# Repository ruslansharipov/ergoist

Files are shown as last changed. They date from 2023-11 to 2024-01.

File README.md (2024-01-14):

# Ergoist
Ergonomic fully split wireless keyboard

Main features: 
- ortholinear layout with 42 keys including 3 keys thumb cluster (just like on corne)
- all keys are 1u to make it easier to find keycaps
- pcb has big cutaway for battery, that can fit 35x30 lipo battery (should fit lipo 503035 500mA)
- designed to be used with Seeduino Xiao
- wireless only. Wired version will be supported it in future
- no screen integration (yet?)
- power switch (longer battery life, no accidental presses during transportation)
- works with ZMK, latest config can be found [here](https://github.com/ruslansharipov/ergoist-zmk-config)
- reversible PCB makes it cheaper in production (usually you can't order less than 5 pieces, so having 5 of those will make you able to assemble 2.5 keyboards)

Status:
- ~~pcb v0.1 in production~~ received, assembled, tested
- case **re**design

Latest images:
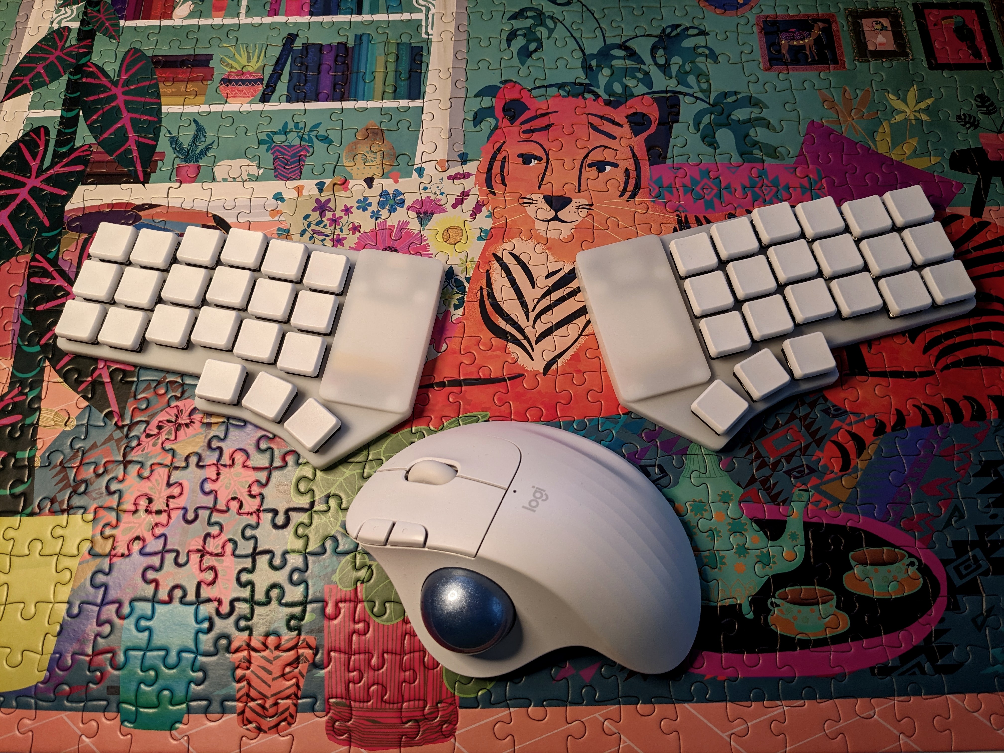
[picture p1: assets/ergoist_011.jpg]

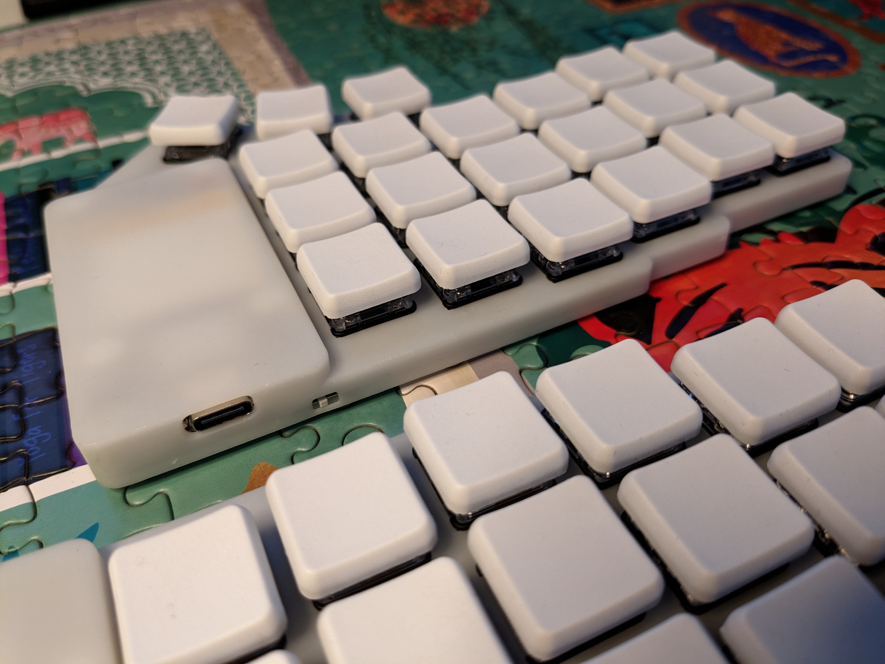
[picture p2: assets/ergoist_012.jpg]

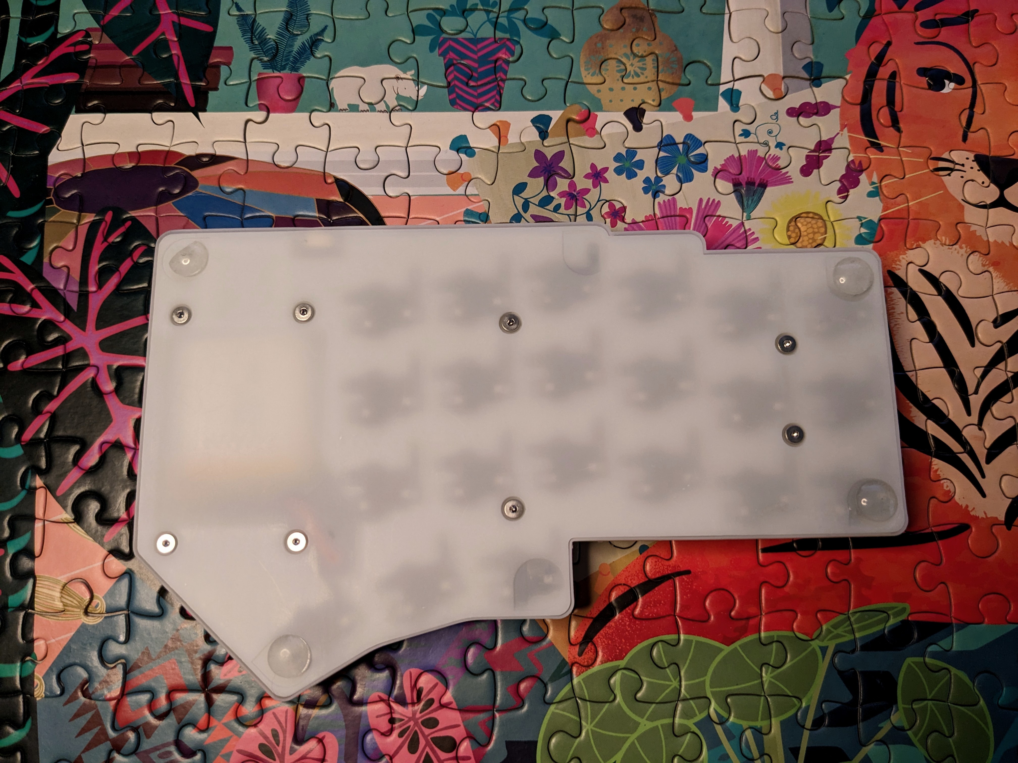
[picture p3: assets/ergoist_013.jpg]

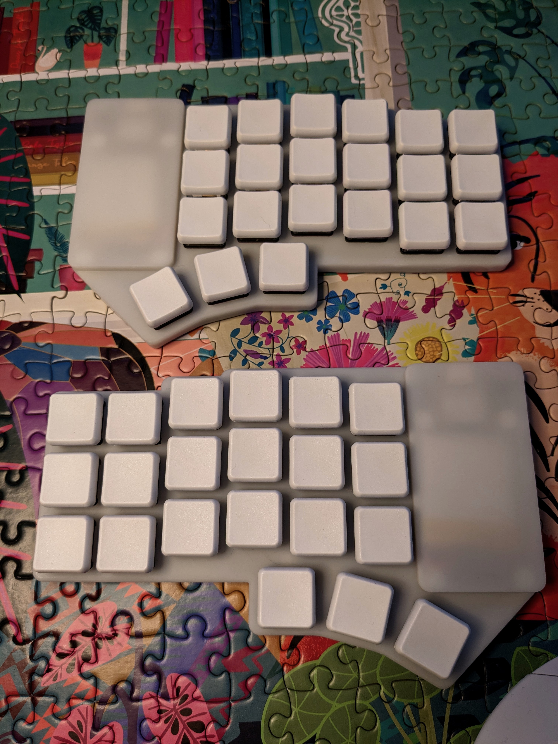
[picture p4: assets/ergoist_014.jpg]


TODO
- update case design
- pcb cleanup
- partlist
- wired version
- screen integration
- touch sensor integration

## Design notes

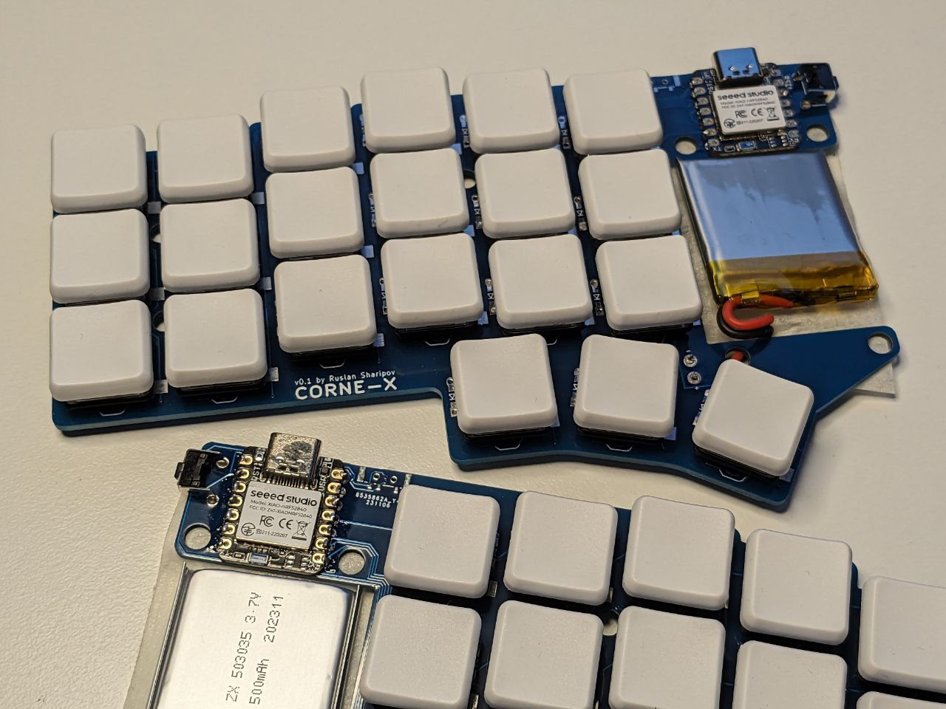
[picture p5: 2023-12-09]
assets/msg270168496-207824.jpg

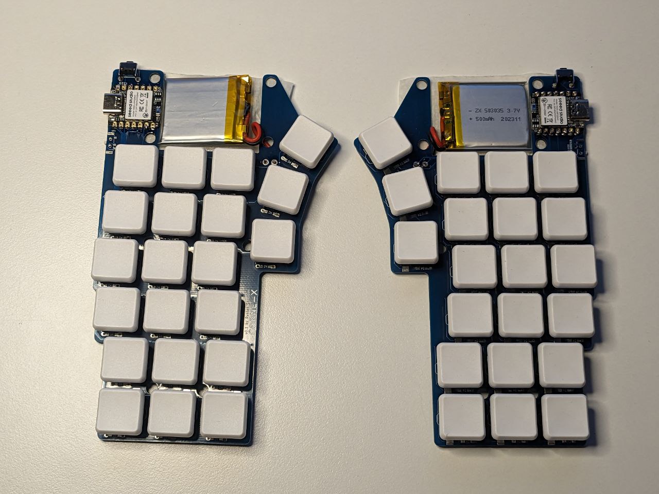
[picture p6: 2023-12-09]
assets/msg270168496-207822.jpg

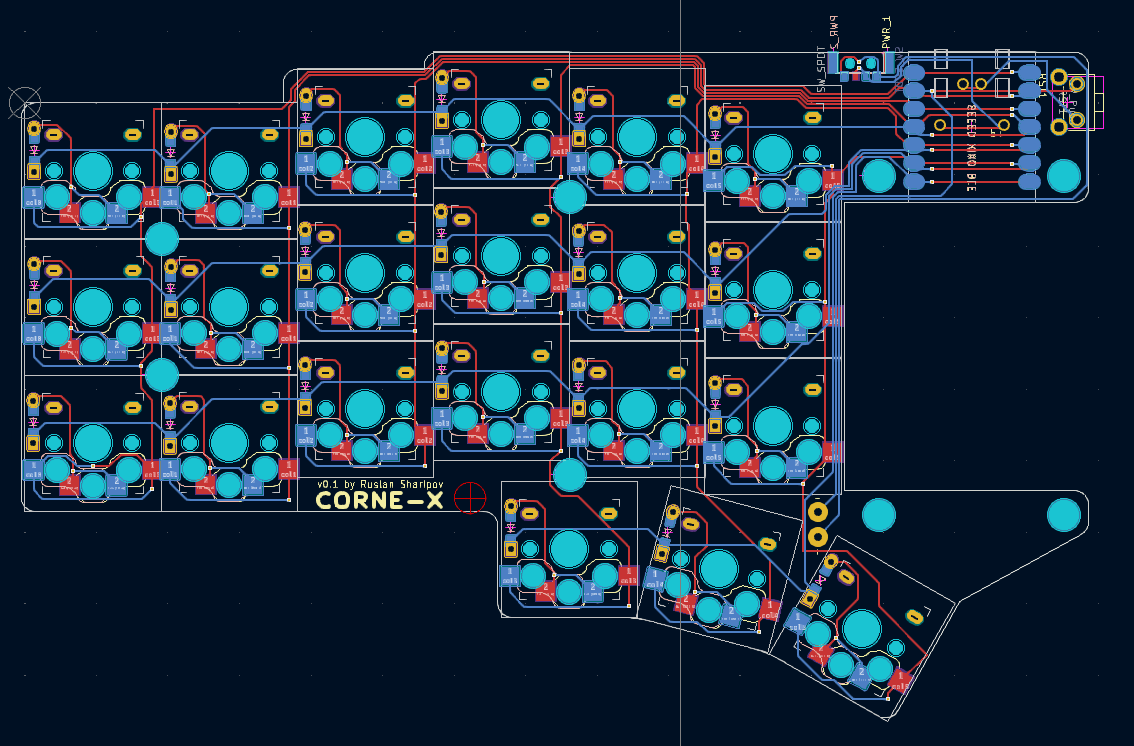
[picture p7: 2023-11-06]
assets/Screenshot 2023-11-06 at 20.16.44.png

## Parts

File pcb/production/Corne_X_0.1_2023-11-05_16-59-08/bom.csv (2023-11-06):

Designator | Footprint | Quantity | Value | LCSC Part #
_8, _7, _6, _5, _4, _3, _2, |  | 8
BAT+1 | BatteryPad | 1 | +
BATGND1 | BatteryPad | 1 | -
D1, D10, D11, D12, D13, D14, D15, D16, D17, D18, D19, D2, D20, D21, D3, D4, D5, D6, D7, D8, D9 | D3_TH_reversible | 21 | D
PWR_1, PWR_2 | MSK12C02 | 2 | SW_SPDT
RST1 | SKHLLCA010_reversible | 1 | SW_Push
SW1, SW10, SW11, SW12, SW13, SW14, SW15, SW16, SW17, SW18, SW19, SW2, SW20, SW21, SW3, SW4, SW5, SW6, SW7, SW8, SW9 | keyswitch_chock12_hotswap_1u_reversible | 21 | SW_PUSH
U1, U4 | xiao-ble-smd-cutout-one-side | 2 | xiao-ble

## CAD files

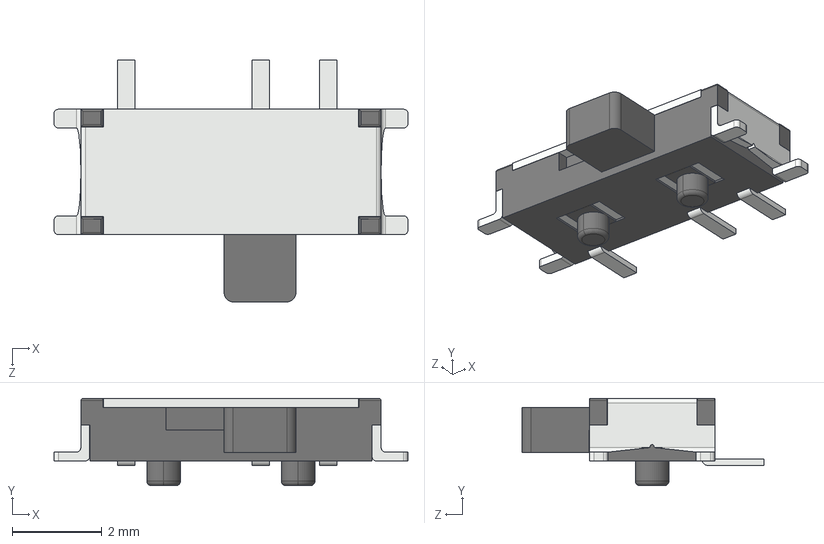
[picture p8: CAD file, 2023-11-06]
pcb/kbd/TOTEM3D/MSK12C02.STEP
7.90 x 1.95 x 5.39 mm

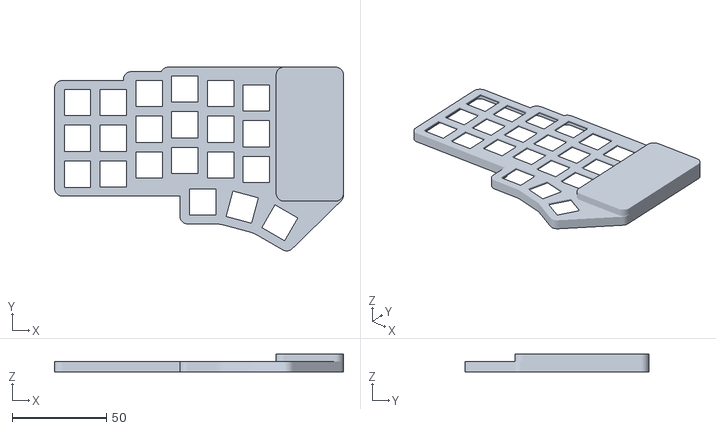
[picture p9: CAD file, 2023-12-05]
pcb/svg/Body11.stl
153.6 x 97.7 x 9.50

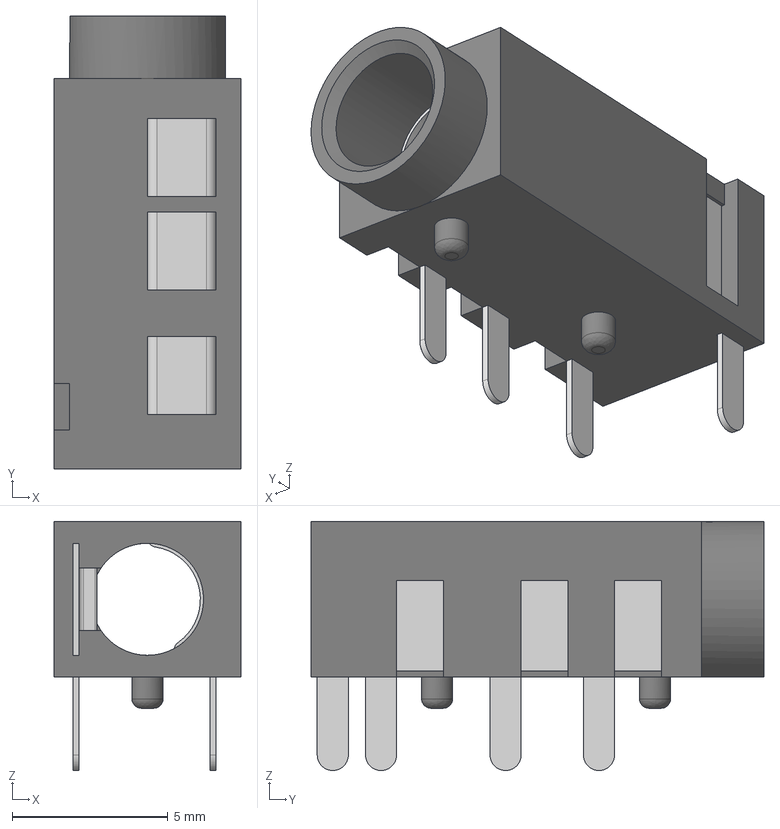
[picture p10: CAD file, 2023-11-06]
pcb/kbd/TOTEM3D/PJ320A.STEP
6.00 x 14.6 x 8.00 mm

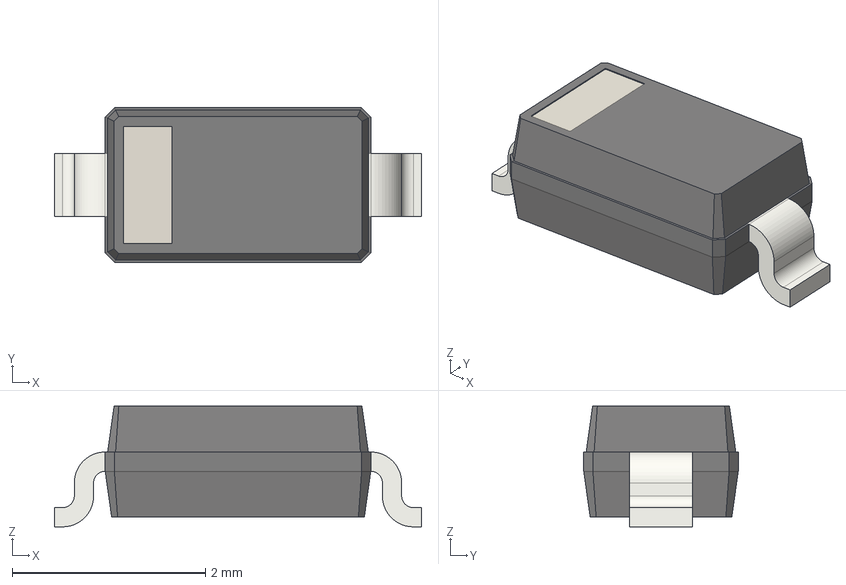
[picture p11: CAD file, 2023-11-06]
pcb/kbd/TOTEM3D/D_SOD-123.step
3.80 x 1.60 x 1.25 mm

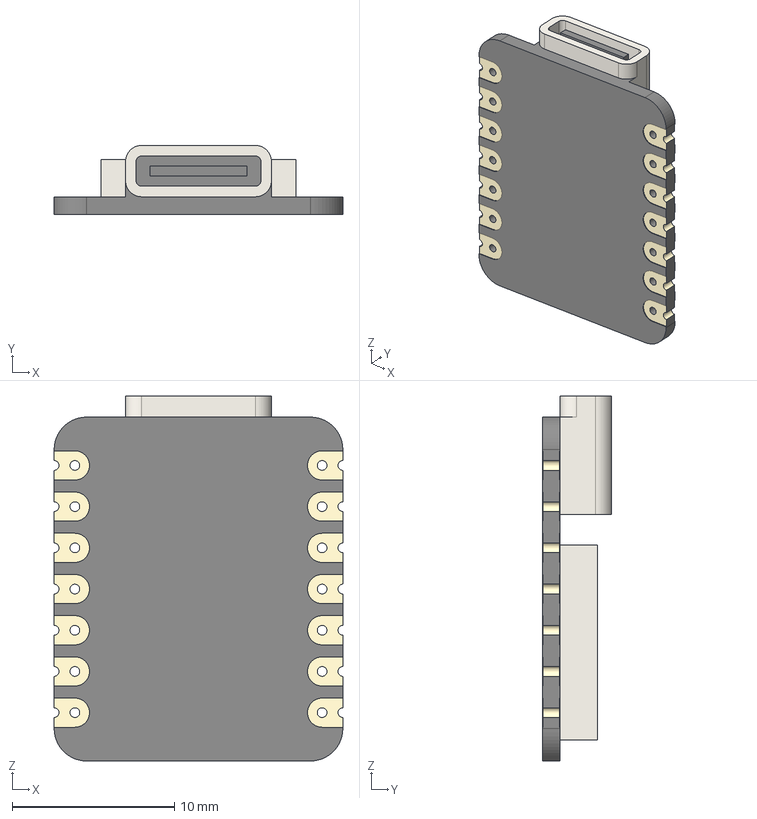
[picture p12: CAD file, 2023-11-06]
pcb/kbd/TOTEM3D/xiao-ble-tht.step
17.8 x 4.27 x 22.5 mm

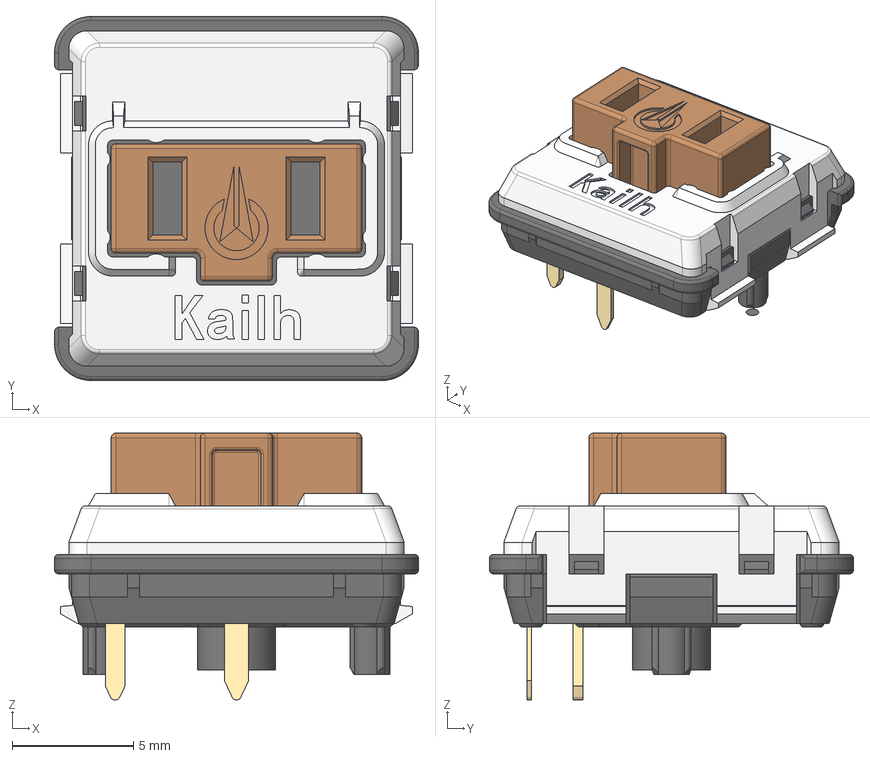
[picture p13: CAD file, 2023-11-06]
pcb/kbd/TOTEM3D/Kailh_switch_PG1350_optional.step
15.0 x 15.0 x 11.0 mm

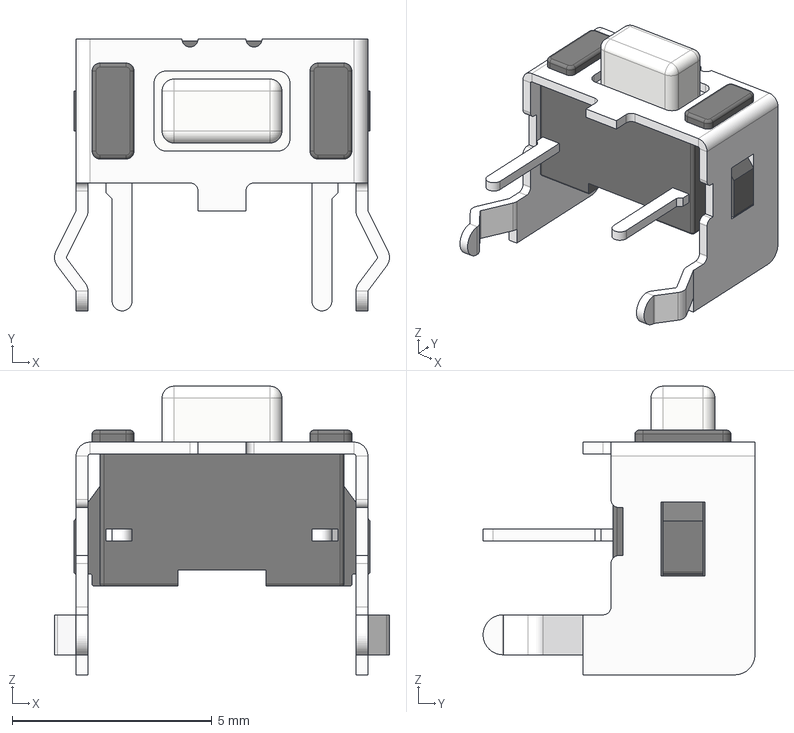
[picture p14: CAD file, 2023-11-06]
pcb/kbd/TOTEM3D/SW_SKHLLC.step
8.38 x 6.80 x 7.22 mm

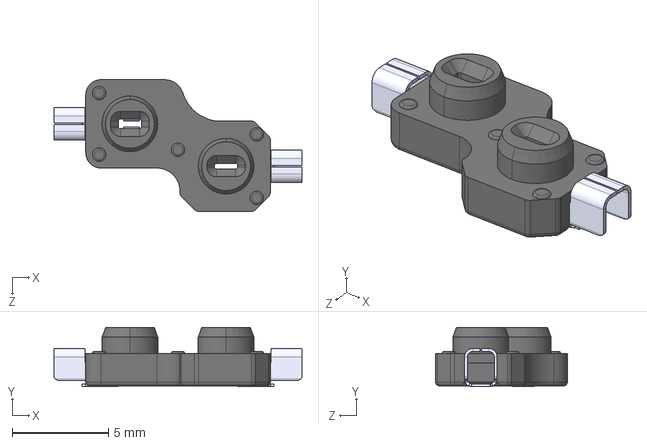
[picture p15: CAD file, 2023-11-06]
pcb/kbd/TOTEM3D/Kailh_socket_PG1350_optional.STEP
12.9 x 3.09 x 6.85 mm
pin x 2
socket

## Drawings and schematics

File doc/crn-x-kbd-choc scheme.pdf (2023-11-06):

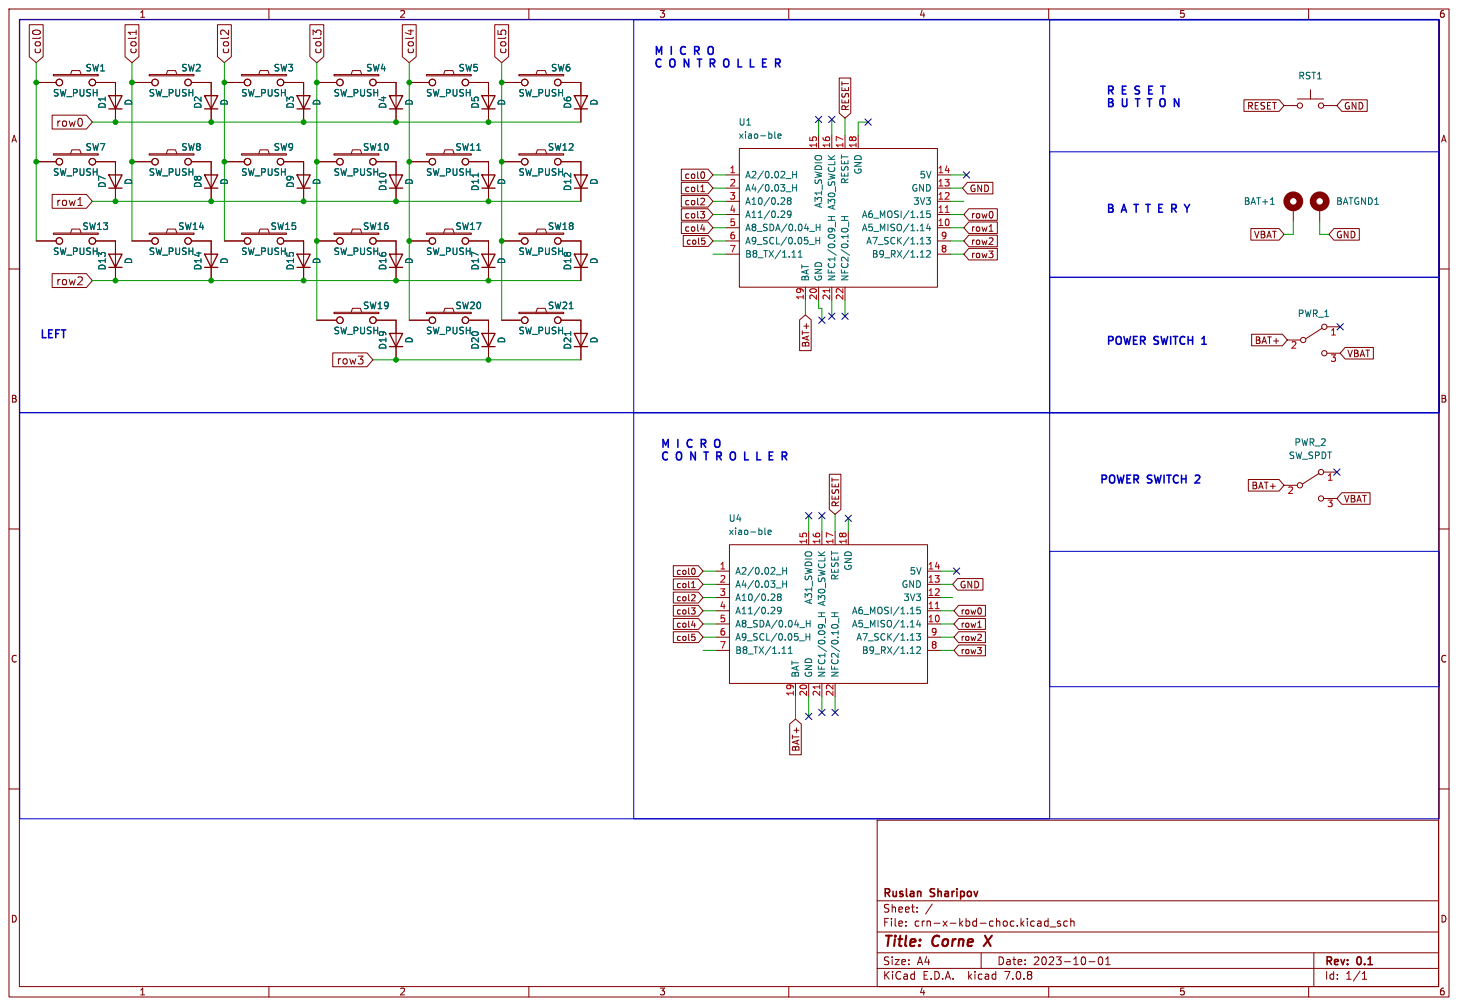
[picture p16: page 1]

POWER SWITCH 1 POWER SWITCH 2 M I C R O

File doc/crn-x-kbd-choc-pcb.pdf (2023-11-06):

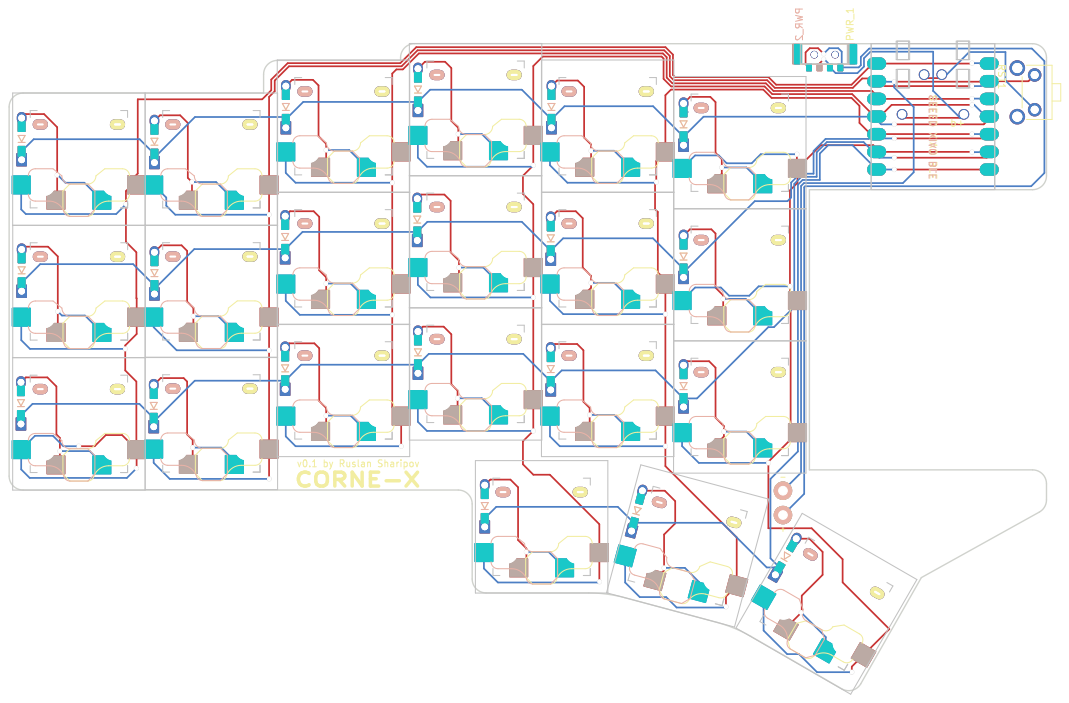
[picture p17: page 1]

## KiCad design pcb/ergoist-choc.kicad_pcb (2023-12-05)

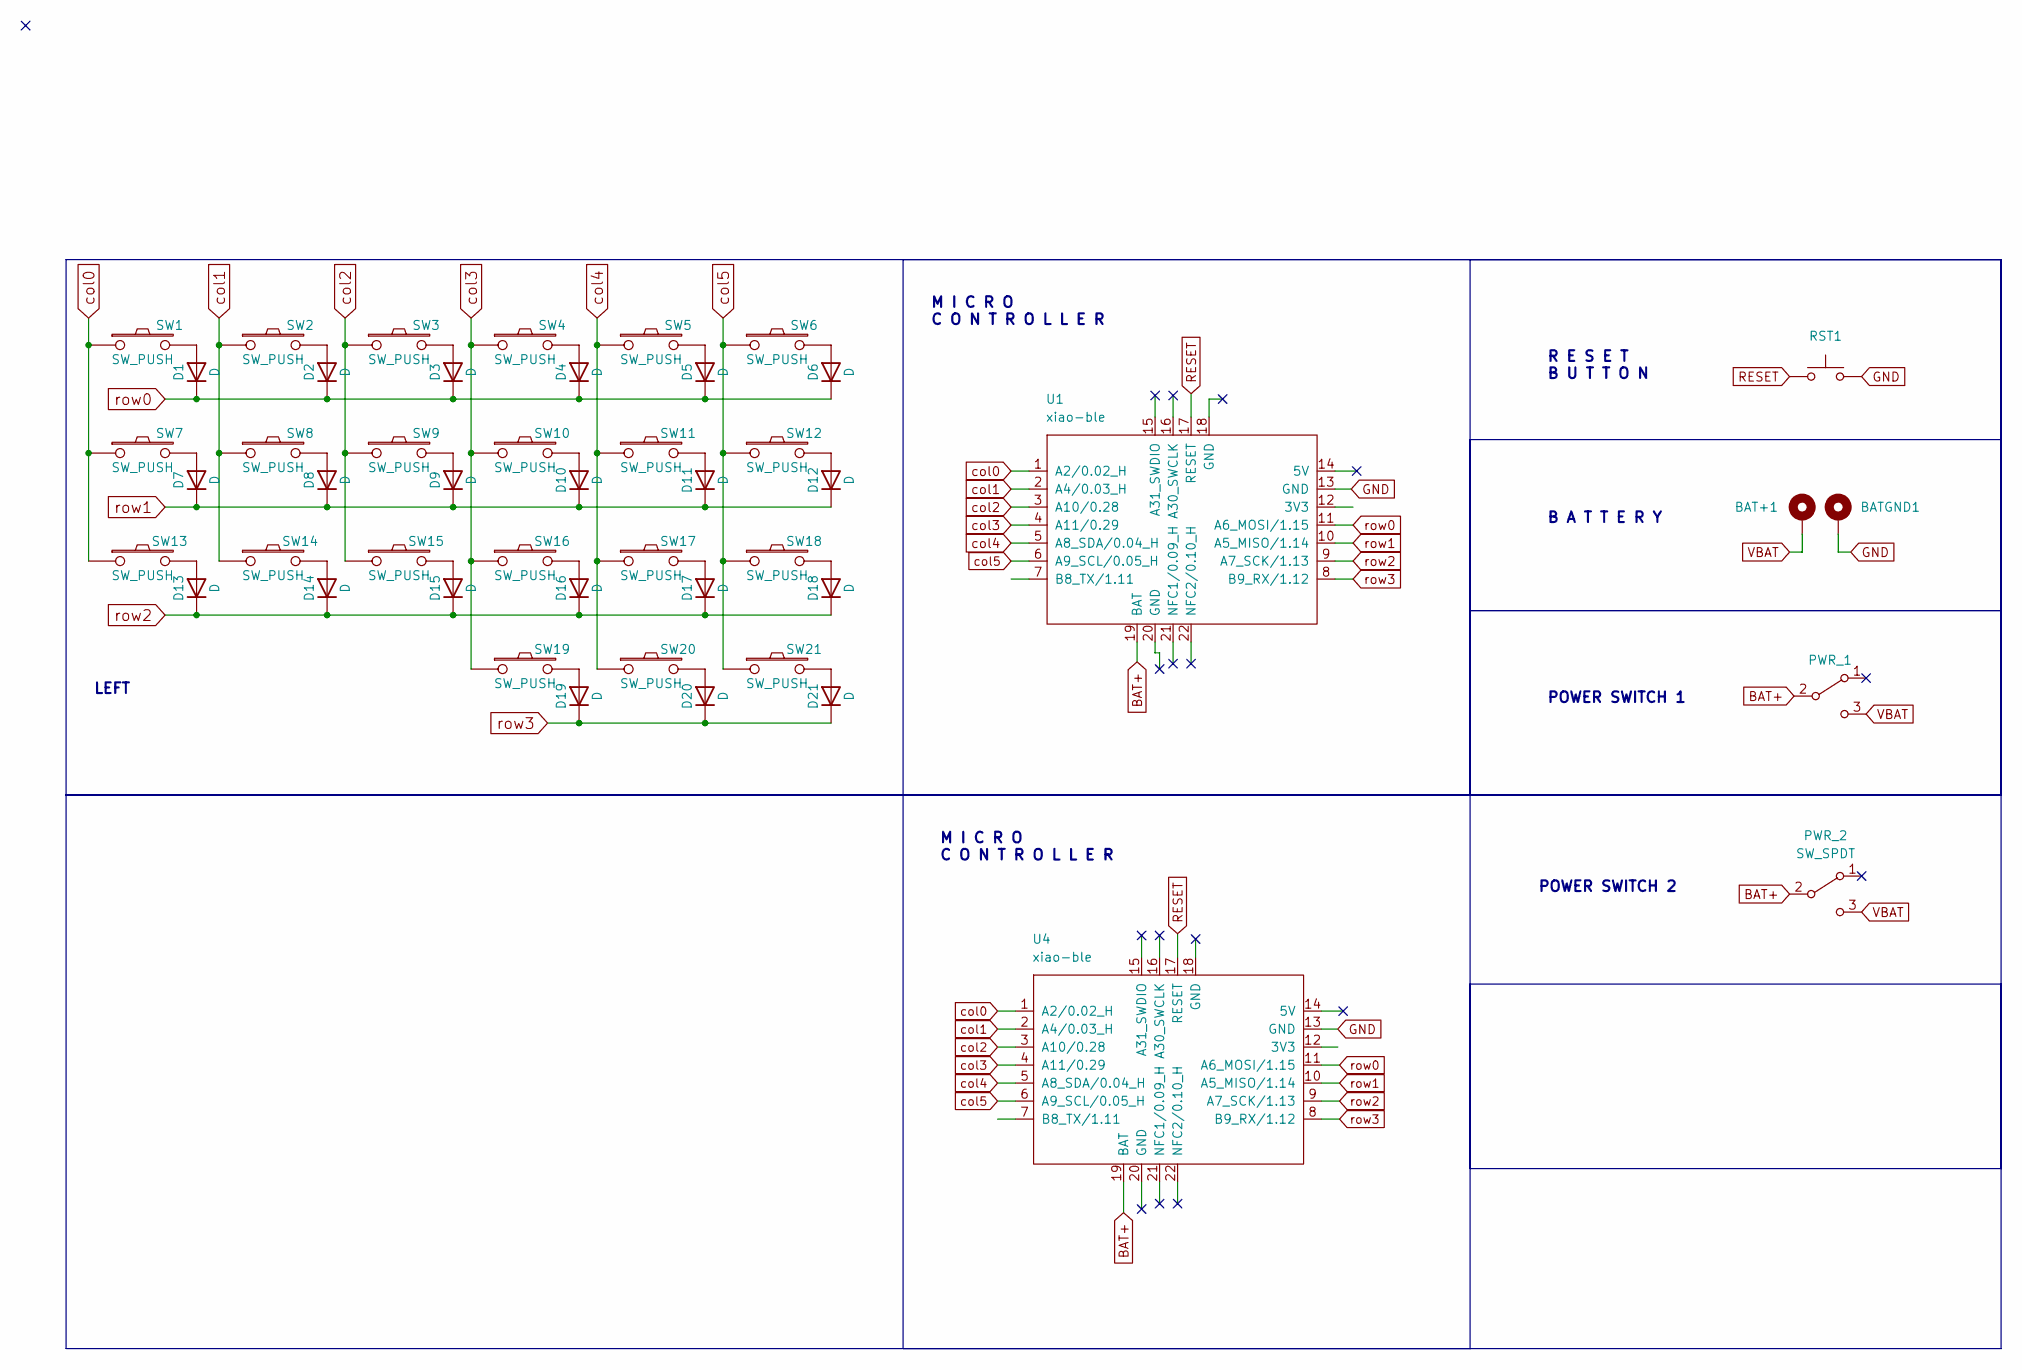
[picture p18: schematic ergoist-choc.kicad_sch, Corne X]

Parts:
BAT+1: +; BatteryPad
BATGND1: -; BatteryPad
D1, D2, D3, D4, D5, D6, D7, D8, D9, D10, D11, D12, D13, D14, D15, D16, D17, D18, D19, D20, D21: D; D3_TH_reversible
PWR_1, PWR_2: SW_SPDT; MSK12C02
RST1: SW_Push; SKHLLCA010_reversible
SW1, SW2, SW3, SW4, SW5, SW6, SW7, SW8, SW9, SW10, SW11, SW12, SW13, SW14, SW15, SW16, SW17, SW18, SW19, SW20, SW21: SW_PUSH; keyswitch_chock12_hotswap_1u_reversible
U1, U4: xiao-ble; xiao-ble-smd-cutout-one-side

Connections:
BAT+: PWR_1.2 (B), PWR_2.2 (B), U1.19 (BAT), U4.19 (BAT)
GND: BATGND1.1, RST1.2, U1.13 (GND), U4.13 (GND)
unnamed: D1.2 (A), SW1.2
unnamed: D2.2 (A), SW2.2
unnamed: D3.2 (A), SW3.2
unnamed: D4.2 (A), SW4.2
unnamed: D5.2 (A), SW5.2
unnamed: D6.2 (A), SW6.2
unnamed: D7.2 (A), SW7.2
unnamed: D8.2 (A), SW8.2
unnamed: D9.2 (A), SW9.2
unnamed: D10.2 (A), SW10.2
unnamed: D11.2 (A), SW11.2
unnamed: D12.2 (A), SW12.2
unnamed: D13.2 (A), SW13.2
unnamed: D14.2 (A), SW14.2
unnamed: D15.2 (A), SW15.2
unnamed: D16.2 (A), SW16.2
unnamed: D17.2 (A), SW17.2
unnamed: D18.2 (A), SW18.2
unnamed: D19.2 (A), SW19.2
unnamed: D20.2 (A), SW20.2
unnamed: D21.2 (A), SW21.2
RESET: RST1.1, U1.17 (RESET), U4.17 (RESET)
VBAT: BAT+1.1, PWR_1.3 (C), PWR_2.3 (C)
col0: SW1.1, SW7.1, SW13.1, U1.1 (A2/0.02_H), U4.1 (A2/0.02_H)
col1: SW2.1, SW8.1, SW14.1, U1.2 (A4/0.03_H), U4.2 (A4/0.03_H)
col2: SW3.1, SW9.1, SW15.1, U1.3 (A10/0.28), U4.3 (A10/0.28)
col3: SW4.1, SW10.1, SW16.1, SW19.1, U1.4 (A11/0.29), U4.4 (A11/0.29)
col4: SW5.1, SW11.1, SW17.1, SW20.1, U1.5 (A8_SDA/0.04_H), U4.5 (A8_SDA/0.04_H)
col5: SW6.1, SW12.1, SW18.1, SW21.1, U1.6 (A9_SCL/0.05_H), U4.6 (A9_SCL/0.05_H)
row0: D1.1 (K), D2.1 (K), D3.1 (K), D4.1 (K), D5.1 (K), D6.1 (K), U1.11 (A6_MOSI/1.15), U4.11 (A6_MOSI/1.15)
row1: D7.1 (K), D8.1 (K), D9.1 (K), D10.1 (K), D11.1 (K), D12.1 (K), U1.10 (A5_MISO/1.14), U4.10 (A5_MISO/1.14)
row2: D13.1 (K), D14.1 (K), D15.1 (K), D16.1 (K), D17.1 (K), D18.1 (K), U1.9 (A7_SCK/1.13), U4.9 (A7_SCK/1.13)
row3: D19.1 (K), D20.1 (K), D21.1 (K), U1.8 (B9_RX/1.12), U4.8 (B9_RX/1.12)

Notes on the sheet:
B A T T E R Y
R E S E T B U T T O N
POWER SWITCH 2
LEFT
M I C R O C O N T R O L L E R
POWER SWITCH 1

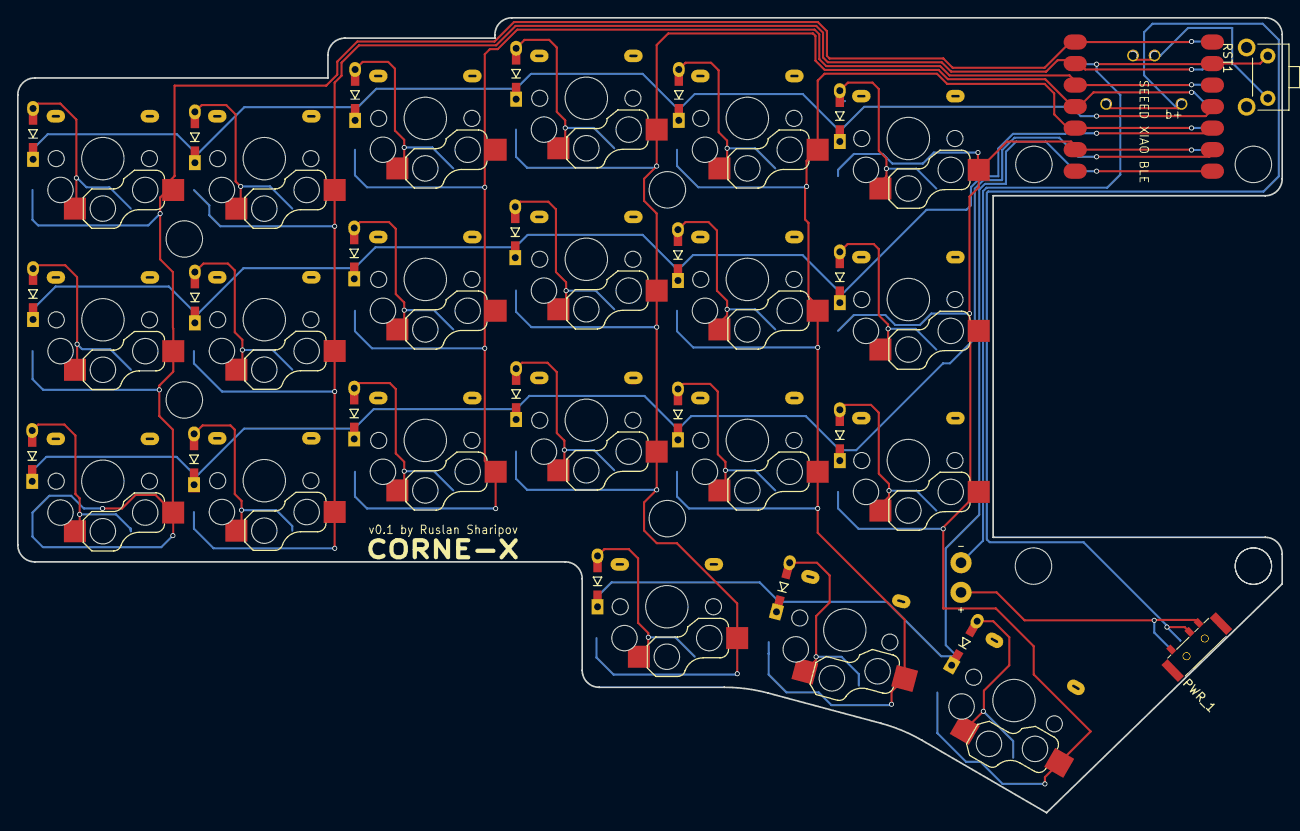
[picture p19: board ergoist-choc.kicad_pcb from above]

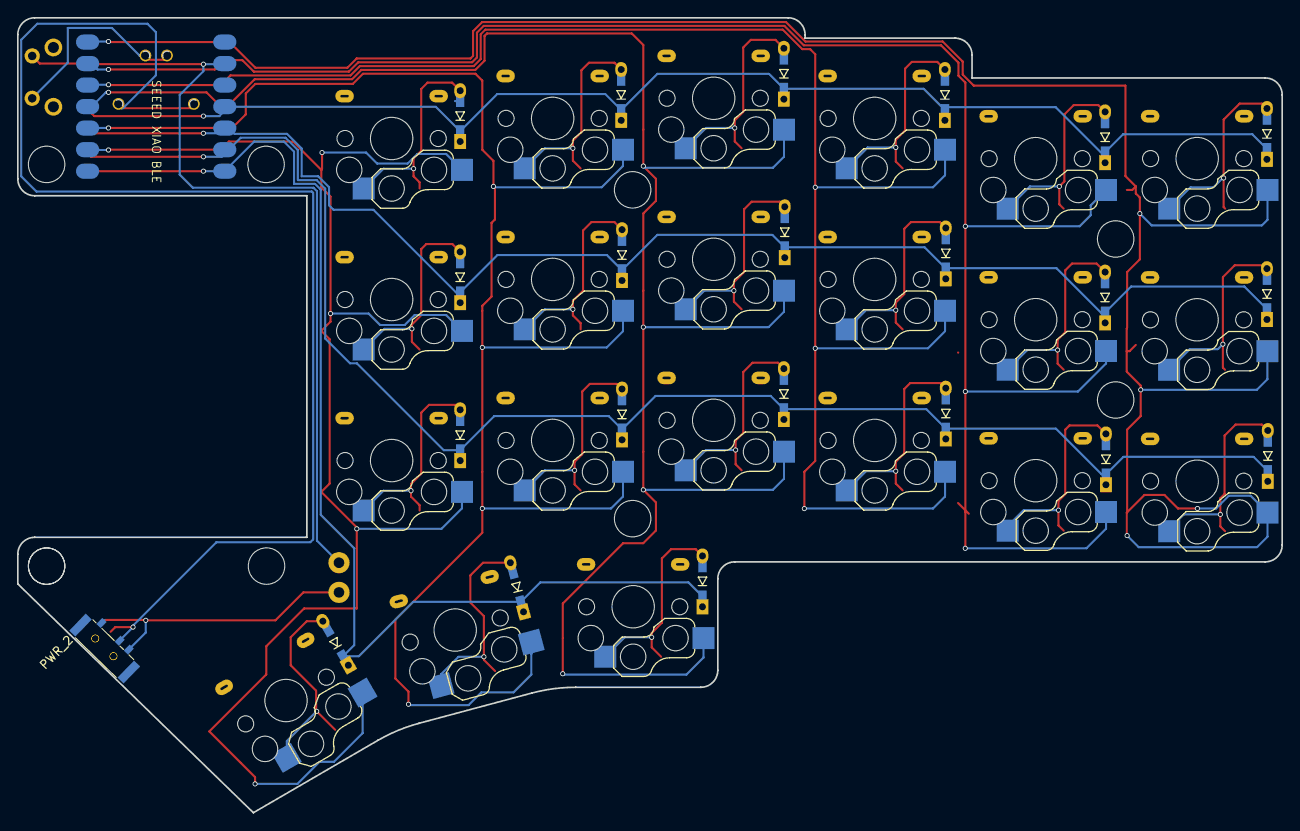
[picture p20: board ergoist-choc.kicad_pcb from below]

Board: 2 copper layers, 149.2 x 93.8 mm, 50 parts (23 on the bottom side), 35 nets.

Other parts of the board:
Ref**: Val**; M2_HOLE_v2
